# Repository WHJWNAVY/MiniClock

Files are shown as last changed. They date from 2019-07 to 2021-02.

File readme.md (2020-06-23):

# MIniClock

## 美图欣赏

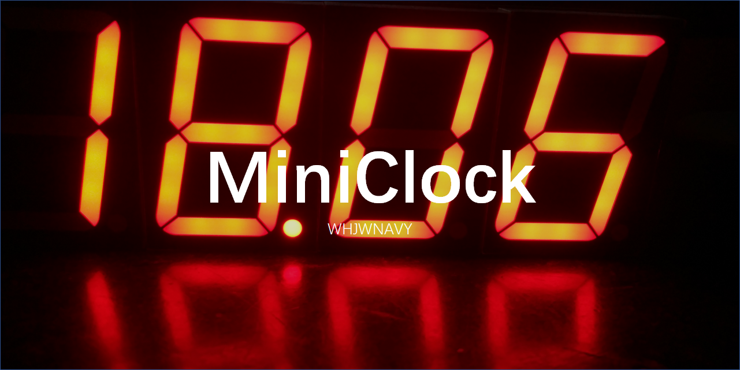
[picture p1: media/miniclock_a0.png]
MiniClock

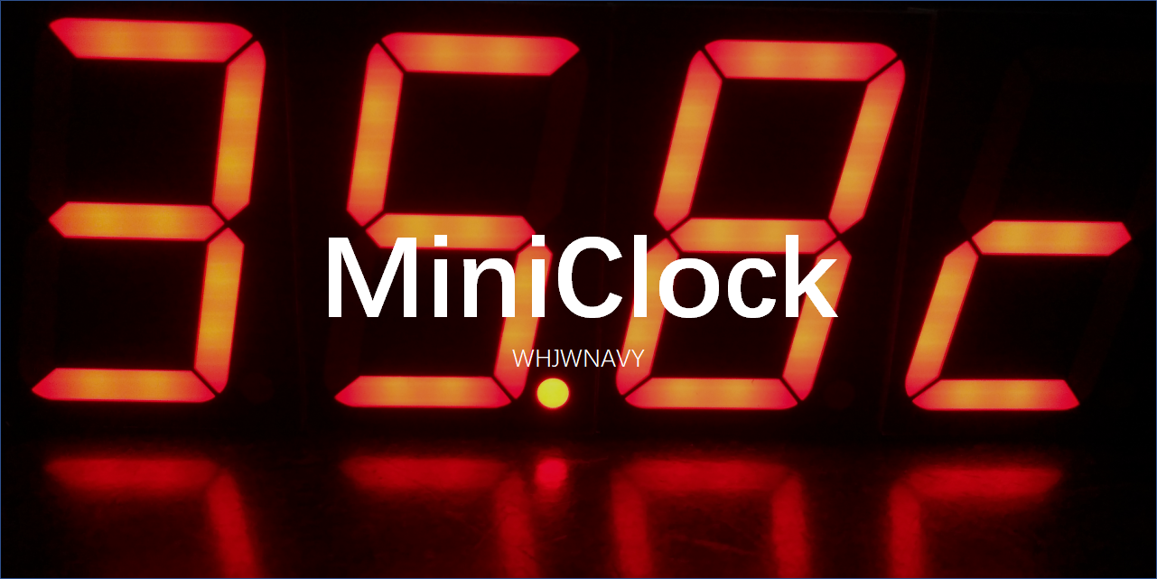
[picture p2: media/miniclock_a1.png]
MiniClock


## 实物图
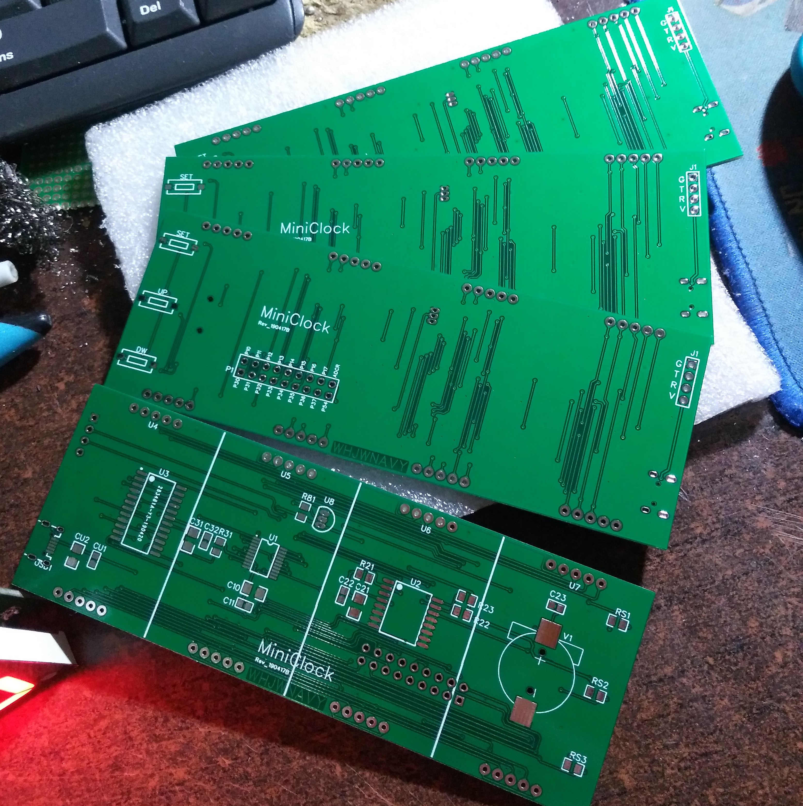
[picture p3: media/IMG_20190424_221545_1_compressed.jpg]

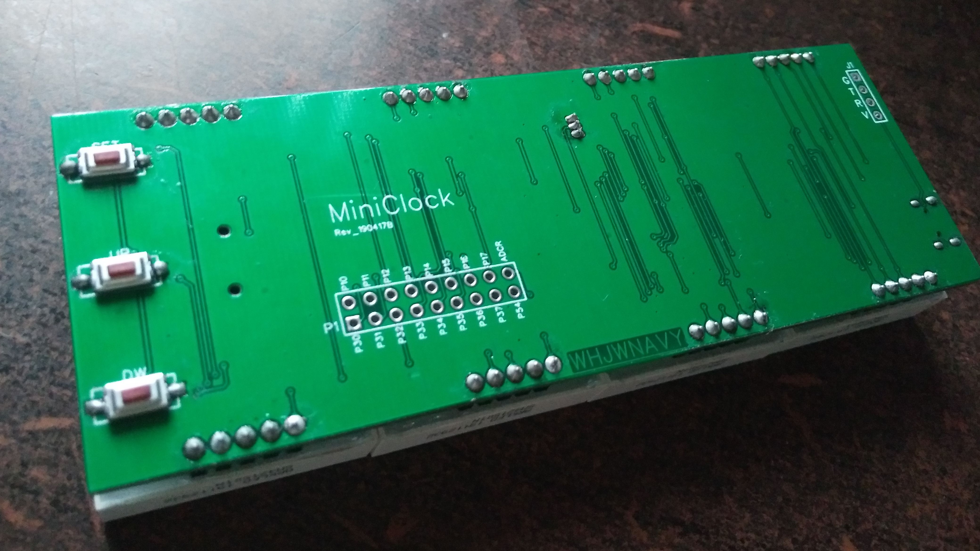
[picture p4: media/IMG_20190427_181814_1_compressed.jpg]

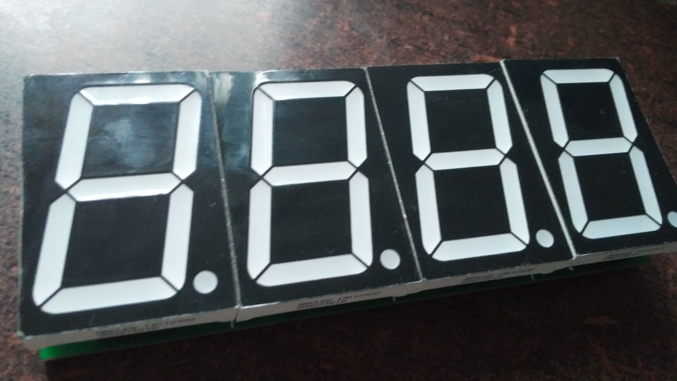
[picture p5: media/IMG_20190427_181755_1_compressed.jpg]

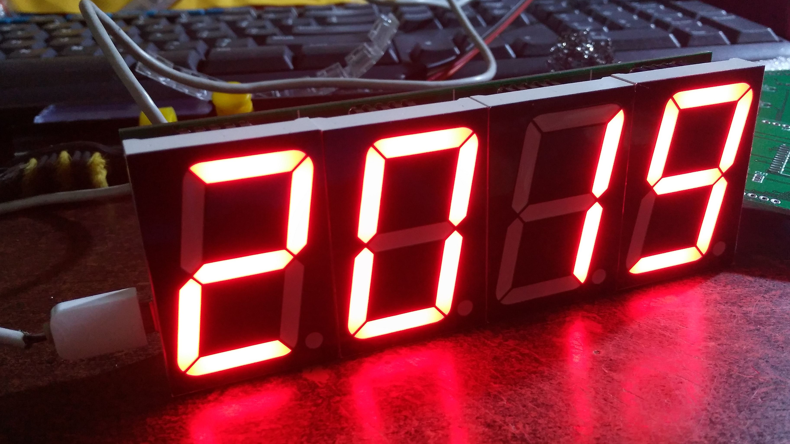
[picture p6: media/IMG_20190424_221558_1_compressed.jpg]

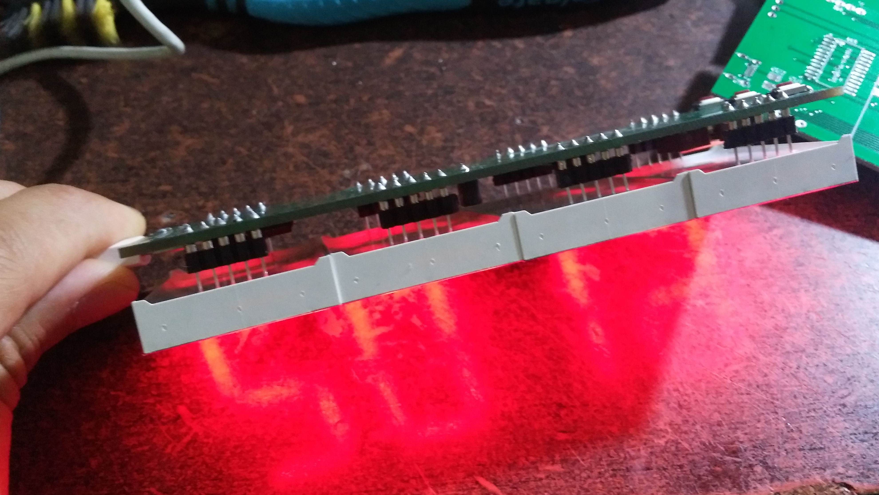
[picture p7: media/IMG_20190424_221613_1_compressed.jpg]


## 原理图&PCB

* ***[MiniClock_SCH_01_190419B.pdf](./doc/MiniClock_SCH_01_190419B.pdf)***

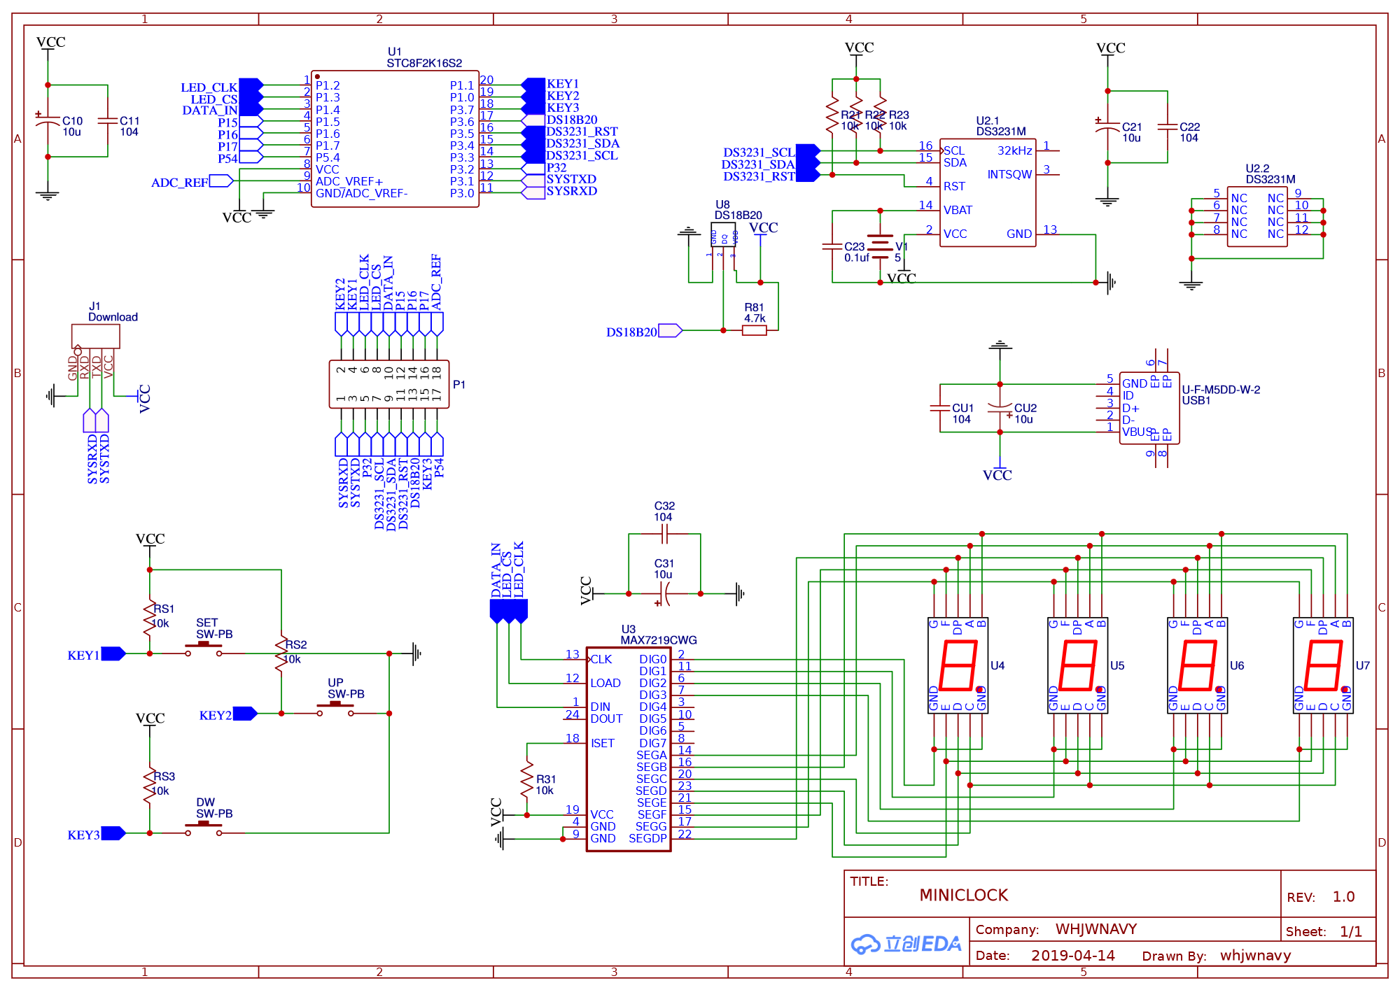
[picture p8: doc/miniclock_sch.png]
MiniClock


* ***[Gerber_MINICLOCK_PCB_02_20190419231404.zip](./doc/MiniClock_PCB_Rev190417B/Gerber_MINICLOCK_PCB_02_20190419231404.zip)***

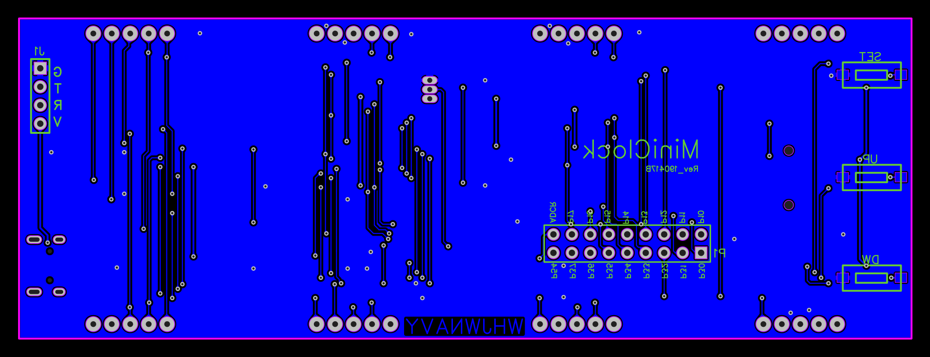
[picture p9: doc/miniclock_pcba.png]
MiniClock

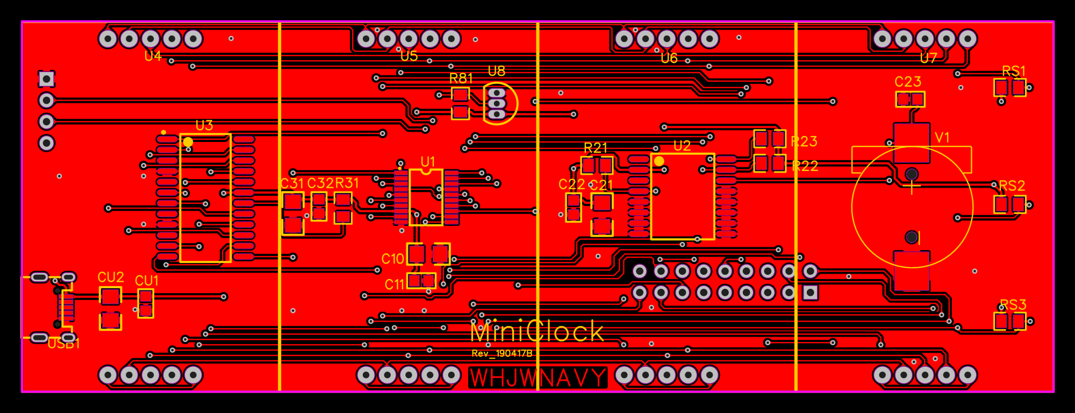
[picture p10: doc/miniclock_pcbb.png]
MiniClock


* ***[LCEDA OpenHW PCB & SCH](https://lceda.cn/whjwnavy/led-miniclock)***

## 页面逻辑

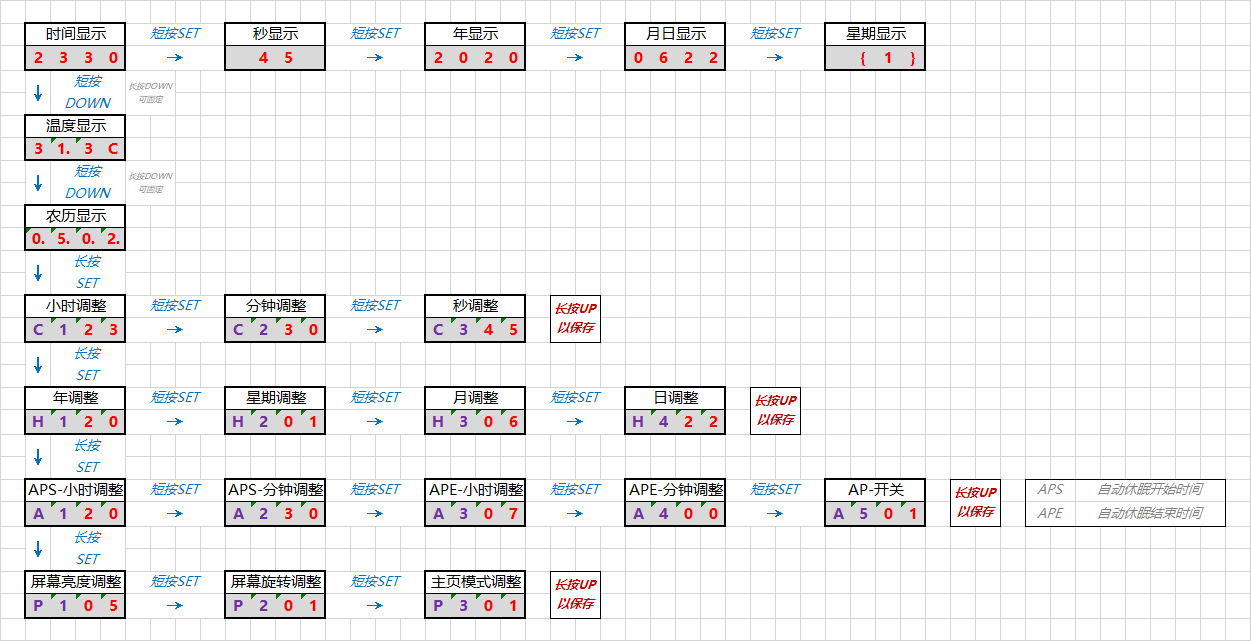
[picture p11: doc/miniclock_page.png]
MiniClock


## 设置代码

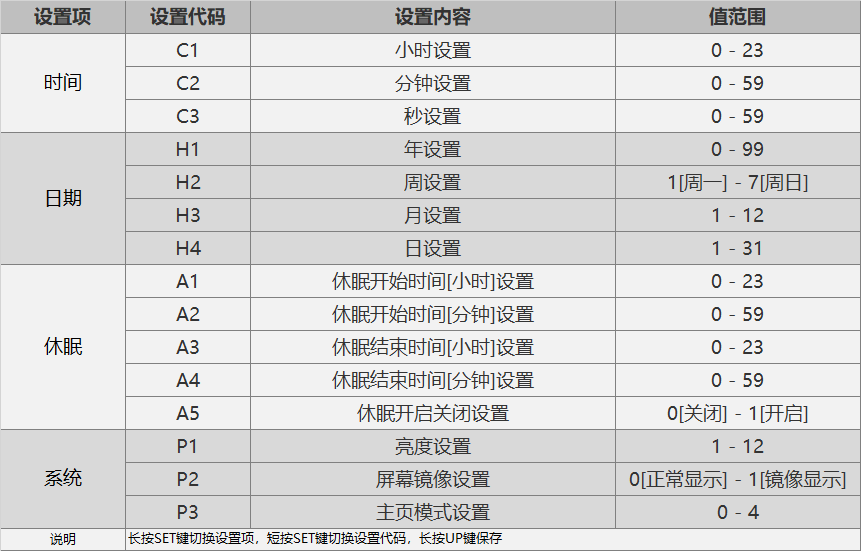
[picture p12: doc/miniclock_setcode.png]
MiniClock


# 使用说明

## 查看

### 查看时间,日历

* 开机后默认显示 **[小时-分钟]** , 底部四个点循环滚动代表秒
* 短按 **Set** 键可以查看 **[秒]**
* 再次短按 **Set** 键可以查看 **[年]**
* 再次短按 **Set** 键可以查看 **[月-日]**
* 再次短按 **Set** 键可以查看 **[星期]** , 1代表周一, 7代表周日
* 15秒内无操作自动回到 **[小时-分钟]** 显示界面

> ***小提示1***
>
> 实际上在 **[小时-分钟]** 显示界面下, 连续短按 **Set** 键, 会依次在 **[小时-分钟] - [秒] - [年] - [月-日] - [星期]** 间循环切换

### 查看温度,农历

* 在 **[小时-分钟]** 显示模式下, 短按 **Up** 键可以查看 **[温度]**
* 再次短按 **Up** 键, 可以查看 **[农历月-日]**
* 在时间显示模式下, 短按 **Dwn** 键可以查看 **[农历月-日]**
* 再次短按 **Dwn** 键, 可以查看 **[温度]**
* 15秒内无操作自动回到 **[小时-分钟]** 显示界面

> ***小提示2***:
>
> 长按(***1秒以上***)一次 **Up** 键可以固定显示温度, 15秒无操作不会退回时间显示界面, 再次短按 **Up*** 或 ***Down** 键可以取消固定

> ***小提示3***
>
> 长按(***1秒以上***)一次 **Dwn** 键可以固定显示农历, 15秒无操作不会退回时间显示界面, 再次短按 **Up*** 或 ***Down** 键可以取消固定

> ***小提示4***
>
> 实际上在 **[小时-分钟]** 显示界面下,连续短按 **Up** 键或 **Dwn** 键, 会依次在 **[小时-分钟] - [温度] - [农历月-日]** 间循环切换

### 待机/休眠模式

* 在 **[小时-分钟]** 显示模式下, 长按(***8秒以上***) **Set** 键可以待机/休眠
* 按任意键结束待机/休眠

## 设置
* 在时间或温度显示界面下, 长按(***1秒以上***) **Set** 键进入 **[设置界面]**
* 设置模式下, 前两位表示 **[设置代码]** ,后两位表示 **[设置值]**
* 设置代码第一位表示 **[主设置项]** , 第二位表示 **[次设置项]**
* 长按(***1秒以上***) **Set** 键切换 **[主设置项]**
* 短按 **Set** 键切换 **[次设置项]**
* 长按(***1秒以上***) **Up** 键保存调整之后的值
* 15秒内无操作自动回到 **[小时-分钟]** 显示界面

> ***小提示5***
>
> 设置值发生改变后会闪烁
>
> 切换主设置项后, 不会自动保存之前的更改
>
> 在 **[系统设置P]** 模式下, 再次长按(***1秒以上***) **Set** 键会回到 **[小时-分钟]** 显示界面

> ***小提示6***
>
> 模式自动休眠开始时间为22:30，结束时间为7:30，MiniClock会在22:30关闭显示界面，直到7:30
>
> MiniClock会在到达你设置的开始时间时关闭显示界面，在到达你设置的结束时间时开启显示界面

> ***小提示7***
>
> 默认的显示模式为正常模式[***0***]，开启旋转显示模式[***1***]后，屏幕内容会旋转180°显示

### 设置代码表

| 主设置项 | 设置代码 | 设置内容 | 值范围 |
| :---: | :---: | :---: | :---: |
| 时间 | C1 | 小时设置 | 0 - 23 |
| | C2 | 分钟设置 | 0 - 59 |
| | C3 | 秒设置 | 0 - 59 |
| 日期 | H1 | 年设置 | 0 - 99 |
| | H2 | 周设置 | 1[周一] - 7[周日] |
| | H3 | 月设置 | 1 - 12 |
| | H4 | 日设置 | 1 - 31 |
| 休眠 | A1 | 休眠开始时间[小时]设置 | 0 - 23 |
| | A2 | 休眠开始时间[分钟]设置 | 0 - 59 |
| | A3 | 休眠结束时间[小时]设置 | 0 - 23 |
| | A4 | 休眠结束时间[分钟]设置 | 0 - 59 |
| | A5 | 休眠开启关闭设置 | 0[关闭] - 1[开启] |
| 系统 | P1 | 亮度设置 | 1 - 12 |
| | P2 | 屏幕镜像设置 | 0[正常显示] - 1[镜像显示] |

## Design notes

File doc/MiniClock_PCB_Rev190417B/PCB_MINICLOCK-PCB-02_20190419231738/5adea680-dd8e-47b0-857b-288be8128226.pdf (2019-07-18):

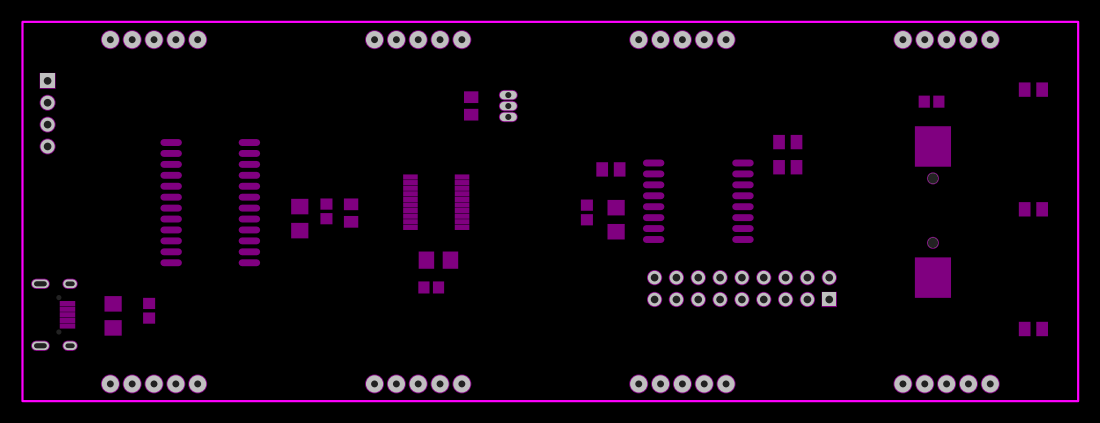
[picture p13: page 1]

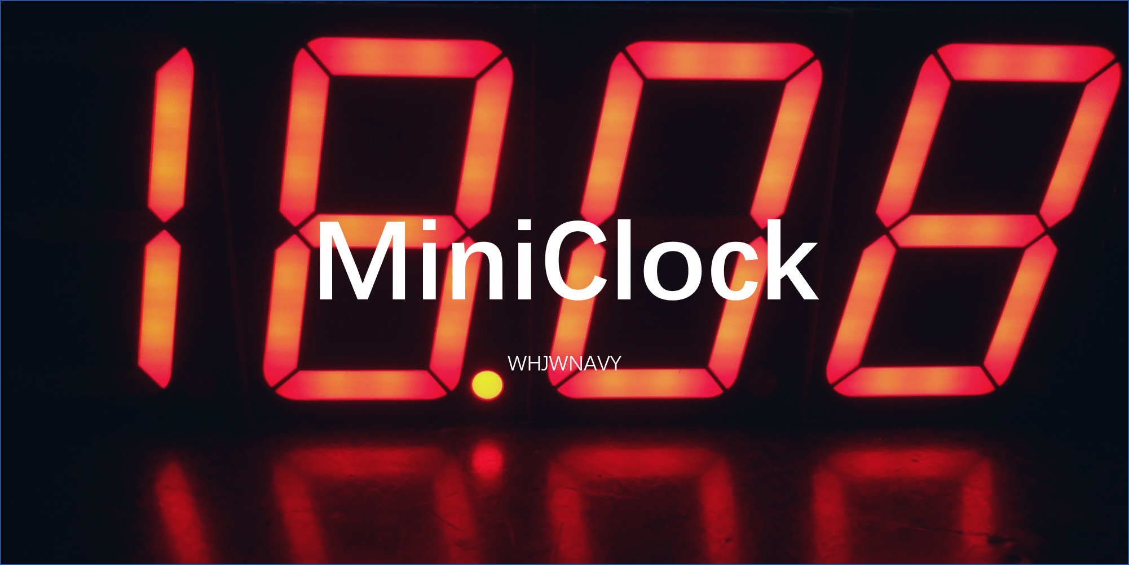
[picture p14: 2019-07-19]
media/MiniClock.png

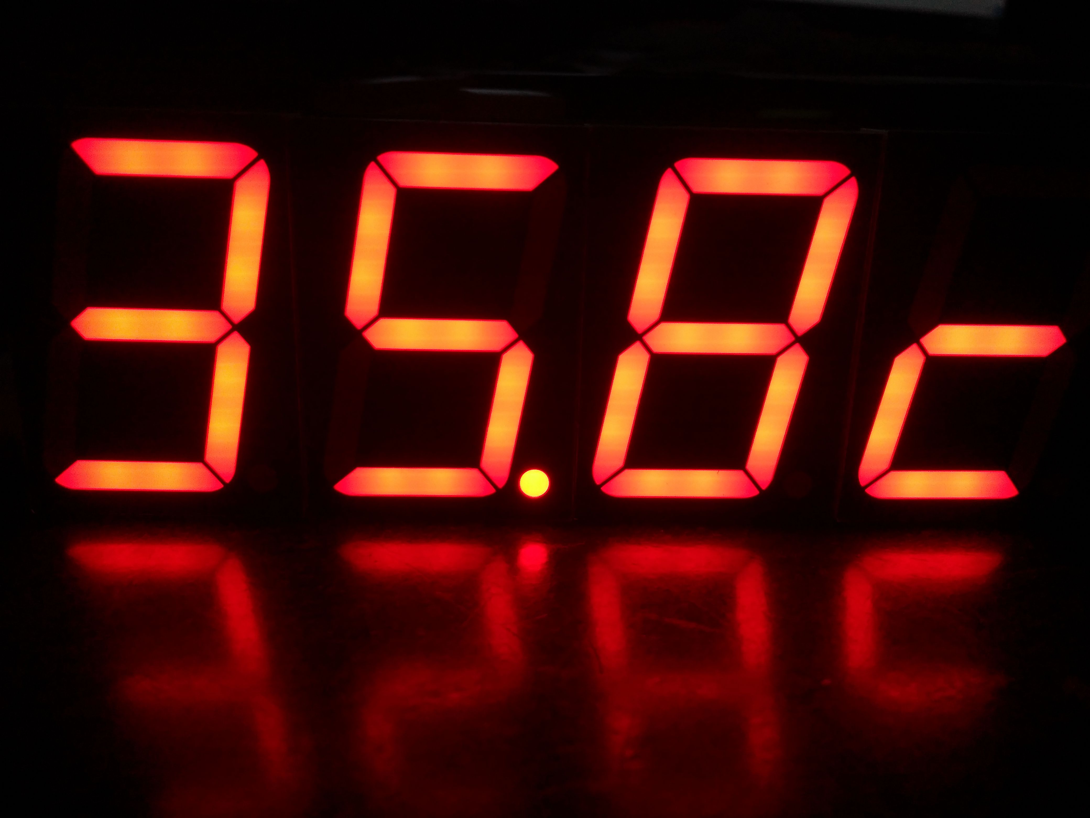
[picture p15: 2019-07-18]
media/IMG_20190427_180651_1_compressed.jpg

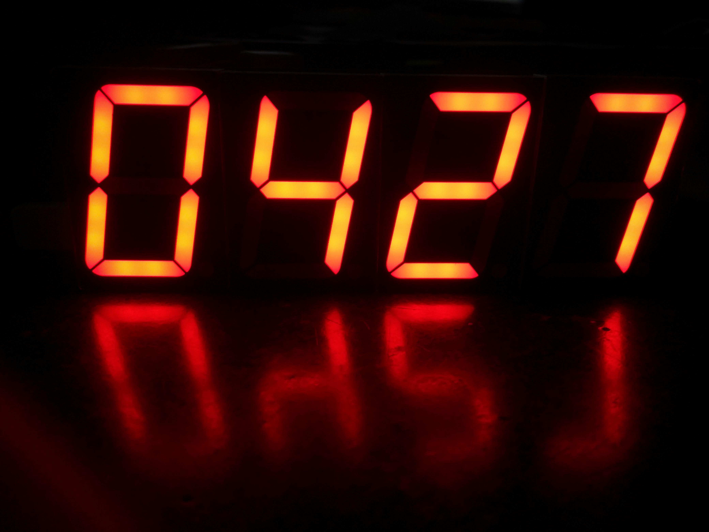
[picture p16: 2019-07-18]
media/IMG_20190427_180931_compressed.jpg

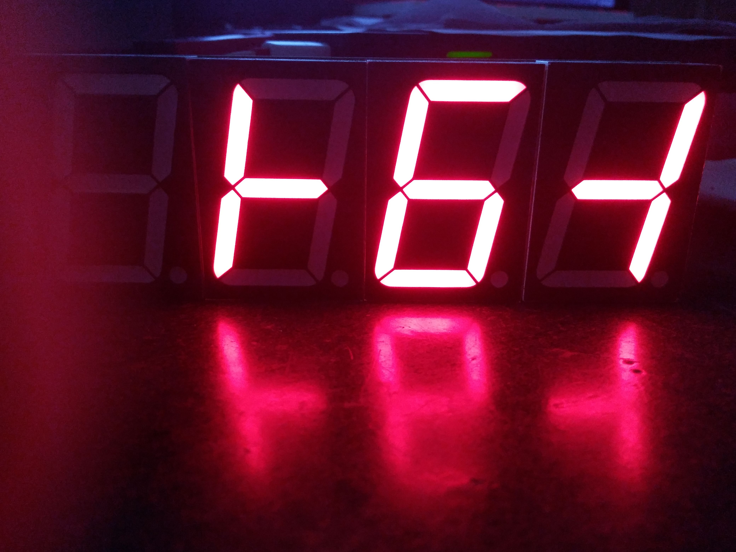
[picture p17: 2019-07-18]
media/IMG_20190427_180738_1_compressed.jpg

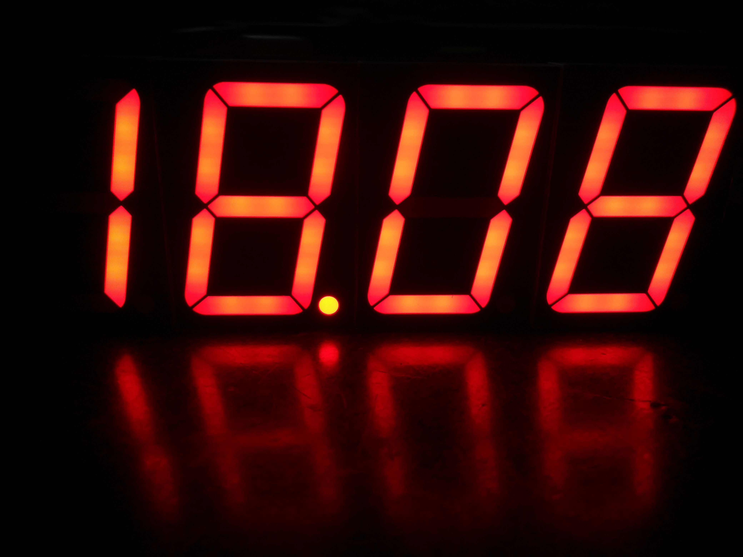
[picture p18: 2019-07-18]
media/MiniClock_big.jpg

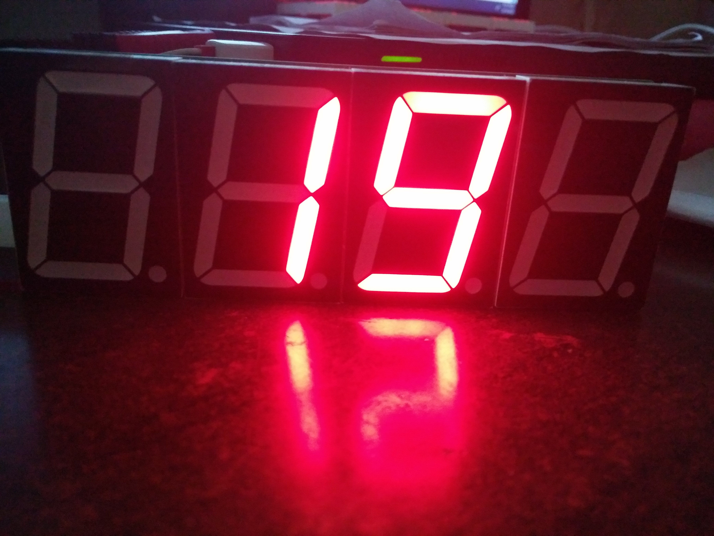
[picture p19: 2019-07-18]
media/IMG_20190427_180916_compressed.jpg

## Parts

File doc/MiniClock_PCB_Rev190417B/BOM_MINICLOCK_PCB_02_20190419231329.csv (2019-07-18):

ID | Name | Designator | Footprint | Quantity | Manufacturer Part | Manufacturer | Supplier | Supplier Part
1 | STC8F2K16S2 | U1 | TSSOP-20 | 1 | STC8F2K16S2 | STC | LCSC | C128772
2 | 10k | R23,R22,R21,R31,RS1,RS2,RS3 | 0805' | 7 | ?
3 | 0.1uf | C23 | C0603 | 1 | ?
4 | 5 | V1 | BATTERY-2 | 1 | ?
5 | 10u | C21,C10,C31,CU2 | 1206 | 4 | ?
6 | 104 | C22,C11,C32,CU1 | C0603 | 4 | ?
7 | MAX7219CWG | U3 | SOIC-24_300MIL | 1 | MAX7219CWG | MAXIM | LCSC | C9964
8 | SW-PB | SET,UP,DW | KEY-3.0*6.0 | 3 | ?
9 | Download | J1 | H4-2.54-UART | 1 | P125-1104A0BS116A1
10 | U-F-M5DD-W-2 | USB1 | MICRO-USB-A17 | 1 | U-F-M5DD-W-2 | HRO | LCSC | C145793
11 | DS18B20 | U8 | 18B20 | 1 | ?
12 | 4.7k | R81 | 0805' | 1 | ?
13 | SM421501 | U4,U5,U6,U7 | SM411501 | 4 | SM411501
14 | Header-Female-2.54_2x9 | P1 | HDR-9X2/2.54 | 1 | Header-Female-2.54_2x9 | BOOMELE | LCSC | C71956
15 | DS3231M | U2 | SOIC-16_300MIL | 1 | DS3231M+TRL | MAXIM | LCSC | C37663

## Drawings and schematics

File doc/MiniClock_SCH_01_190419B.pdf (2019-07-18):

## VCC VCC

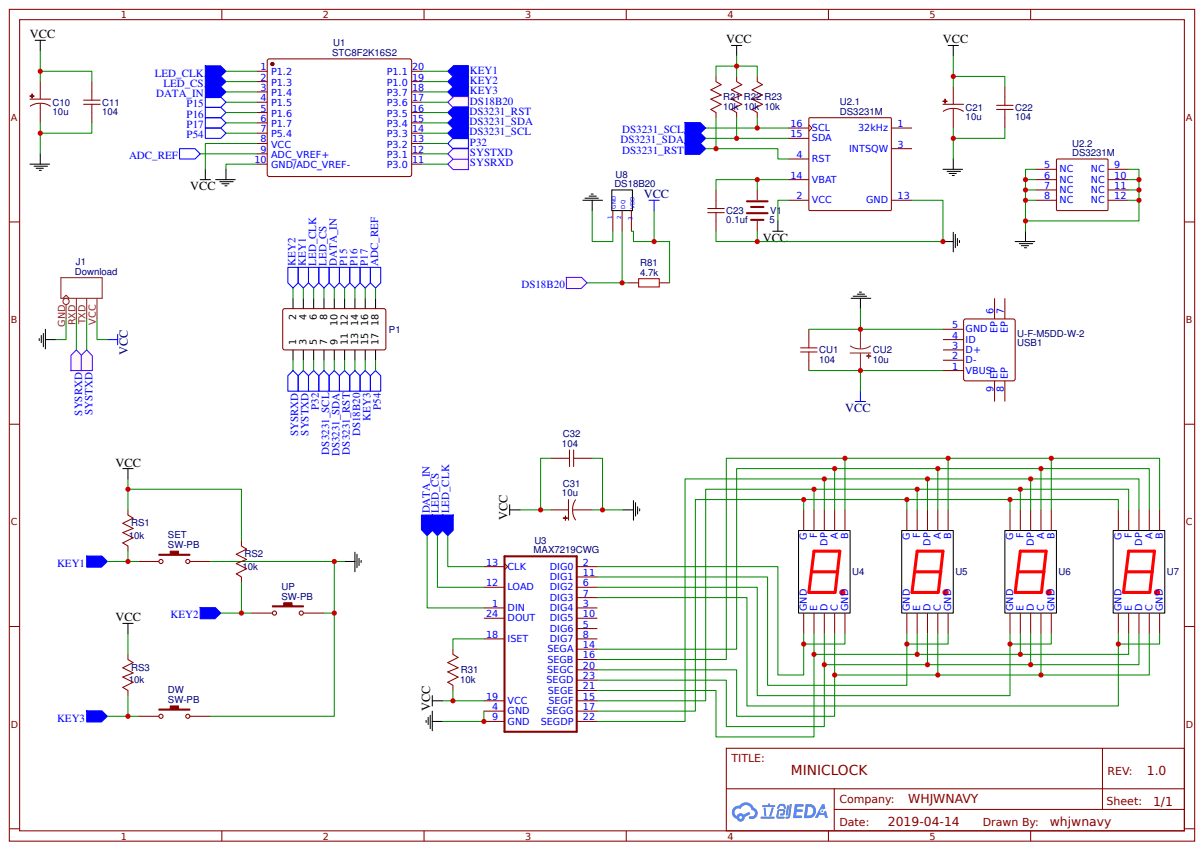
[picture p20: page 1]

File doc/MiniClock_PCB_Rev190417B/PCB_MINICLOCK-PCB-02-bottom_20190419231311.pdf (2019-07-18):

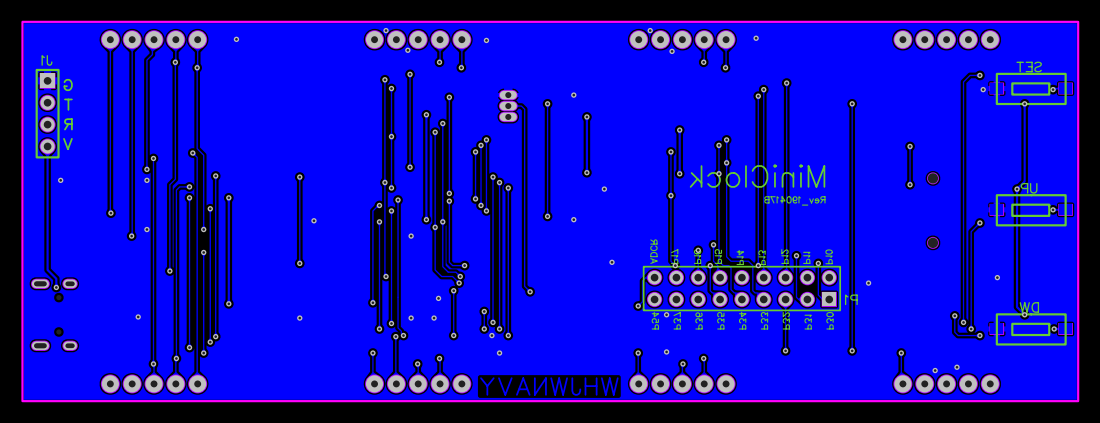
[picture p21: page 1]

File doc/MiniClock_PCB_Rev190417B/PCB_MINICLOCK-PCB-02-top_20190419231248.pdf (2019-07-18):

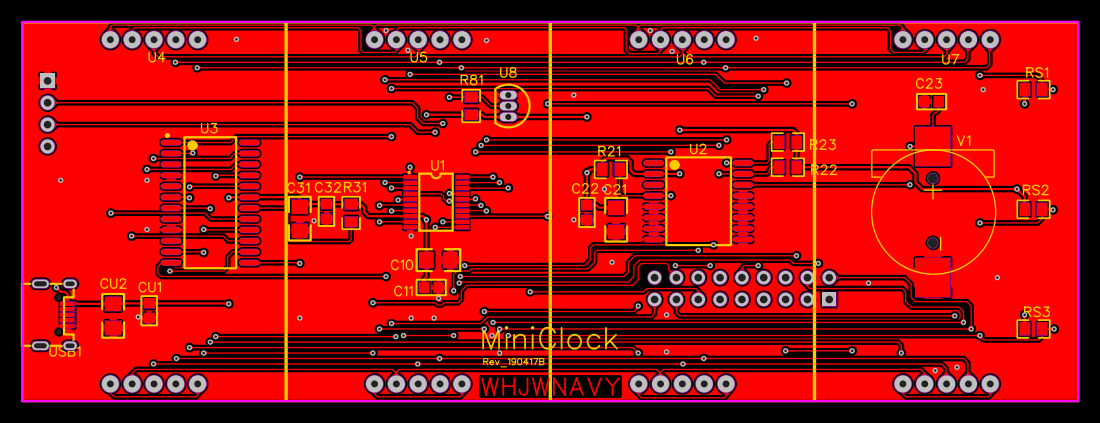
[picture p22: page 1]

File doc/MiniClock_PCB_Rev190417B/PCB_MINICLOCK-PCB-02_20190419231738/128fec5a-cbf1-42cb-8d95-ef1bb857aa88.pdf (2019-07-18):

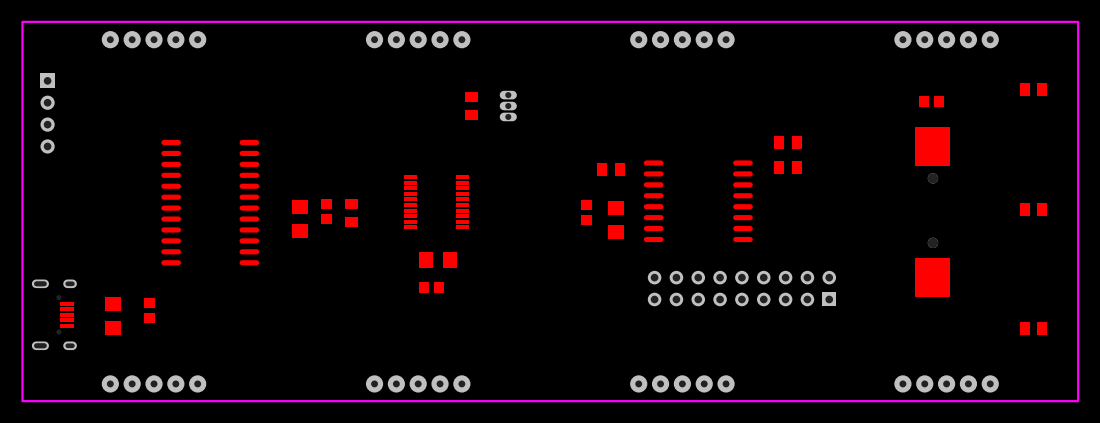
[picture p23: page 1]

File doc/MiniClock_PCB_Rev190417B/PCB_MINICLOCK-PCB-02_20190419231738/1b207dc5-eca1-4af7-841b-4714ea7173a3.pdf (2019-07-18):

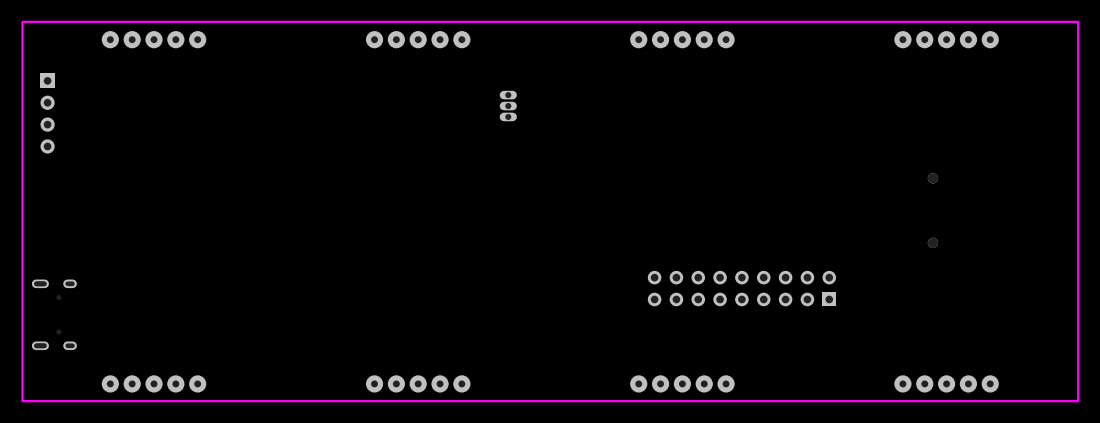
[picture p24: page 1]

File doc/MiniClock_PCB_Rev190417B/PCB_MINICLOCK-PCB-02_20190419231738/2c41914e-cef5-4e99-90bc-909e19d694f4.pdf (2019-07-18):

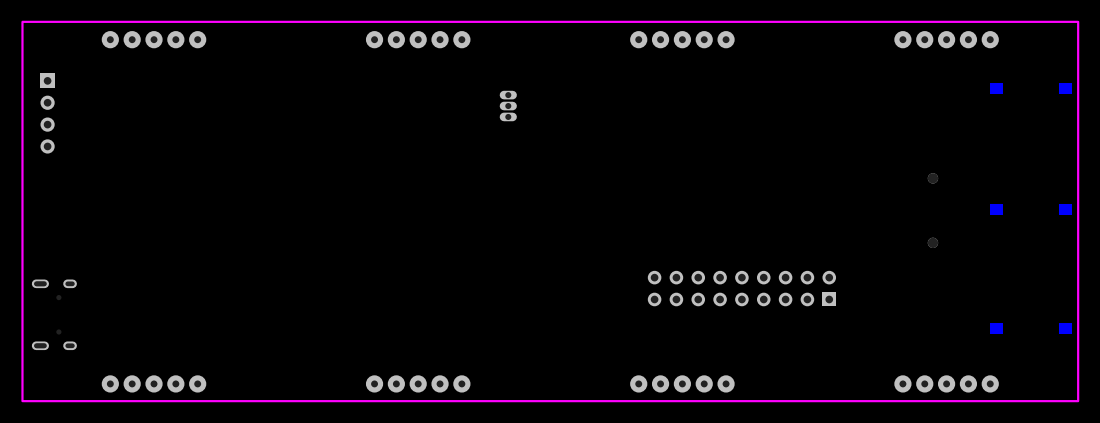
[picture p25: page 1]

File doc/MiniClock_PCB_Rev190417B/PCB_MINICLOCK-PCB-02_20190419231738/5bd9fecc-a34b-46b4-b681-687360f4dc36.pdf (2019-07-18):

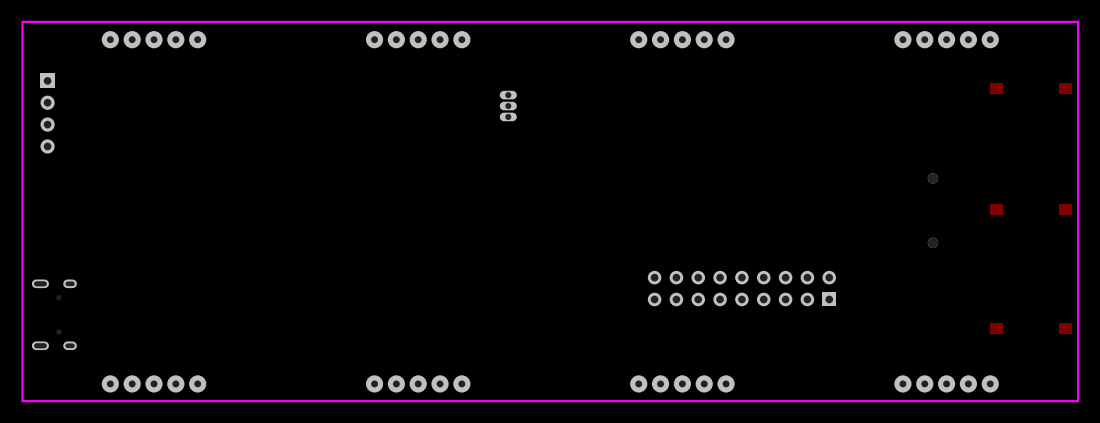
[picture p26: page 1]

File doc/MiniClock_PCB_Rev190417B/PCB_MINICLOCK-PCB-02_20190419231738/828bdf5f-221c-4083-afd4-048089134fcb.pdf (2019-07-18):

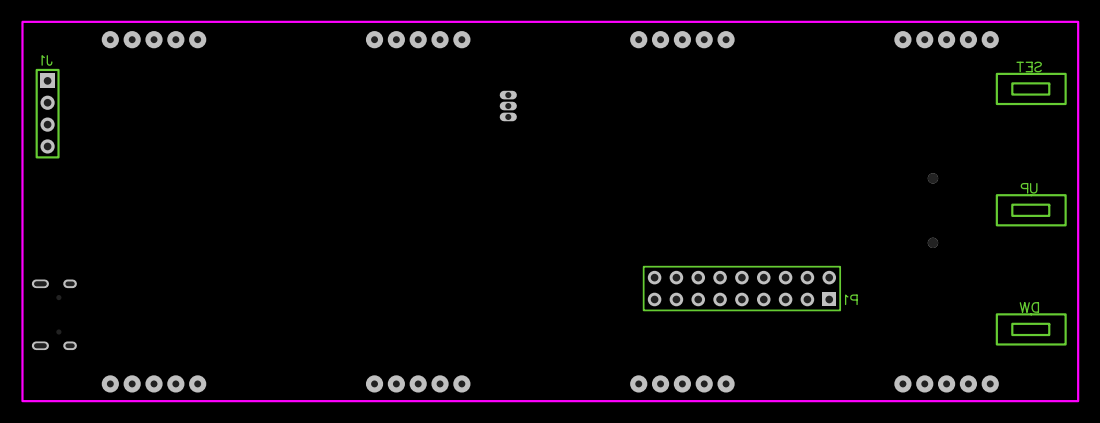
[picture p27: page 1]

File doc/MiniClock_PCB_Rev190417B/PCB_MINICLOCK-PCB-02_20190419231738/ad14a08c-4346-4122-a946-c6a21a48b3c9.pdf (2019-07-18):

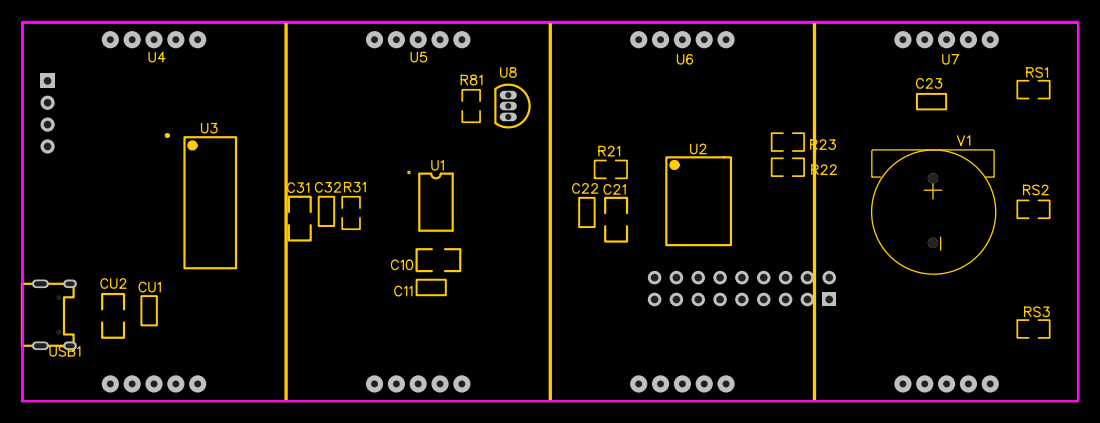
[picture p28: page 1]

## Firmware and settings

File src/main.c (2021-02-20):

#include "common.h"
#include "drv_led.h"
#include "drv_key.h"
#include "drv_3231.h"
#include "china_nonli.h"
#include "drv_18b20.h"

#include "drv_cfg.h"

#define DEF_SYS_LED_FPS (100u)
#define DEF_SYS_LED_FLASH (3u)
#define DEF_SYS_LED_MIRROR (0u)

#define DEF_SYS_MAIN_MODE (4u)
#define SYS_MAIN_MODE_MAX (4u)

#define DEF_SYS_AUTOEXIT_TMR (150u)
#define DEF_SYS_LED_LIGHT (5u)
#define DEF_SYS_AUTO_SLEEP (1u)

#define DEF_SYS_REMIND_DELAY (20u)
#define DEF_SYS_REMIND_TMR (10u)

//菜单列表
typedef enum page_mode_e {
    PAGE_MENU_MIN = 0x1Au,
    PAGE_MENU_MAIN = PAGE_MENU_MIN, //主界面
    PAGE_MENU_STIME,                //时间设置界面
    PAGE_MENU_SDATE,                //日期设置界面
    PAGE_MENU_SATSLEEP,             //自动休眠设置
    PAGE_MENU_SYSCFG,               //系统设置
    PAGE_MENU_MAX,
    PAGE_MENU_POWER,
    PAGE_MENU_REMIND,
} page_mode_e;

//计时模式
typedef enum main_mode_e {
    MAIN_MODE_MIN = 0x20u,
    MAIN_MODE_TIME = MAIN_MODE_MIN, // time
    MAIN_MODE_TEMP,                 // temp
    MAIN_MODE_NONLI,                // nonli
    MAIN_MODE_MAX,
} main_mode_t;

//主页切换
typedef enum main_page_e {
    MAIN_PAGE_MIN = 0x2Au,
    MAIN_PAGE_HHMM = MAIN_PAGE_MIN, // hour - minute
    MAIN_PAGE_TTSS,                 // am/pm - second
    MAIN_PAGE_YYYY,                 // year
    MAIN_PAGE_MMDD,                 // month - day
    MAIN_PAGE_DDDD,                 // week
    MAIN_PAGE_MAX,
} main_page_t;

//时间设置界面
typedef enum set_time_page_e {
    SET_TIME_PAGE_MIN = 0x3Au,
    SET_TIME_PAGE_HOUR = SET_TIME_PAGE_MIN, // hour
    SET_TIME_PAGE_MINUTE,                   // minute
    SET_TIME_PAGE_SECOND,                   // second
    SET_TIME_PAGE_MAX,
} set_time_page_t;

//日期设置界面
typedef enum set_date_page_e {
    SET_DATE_PAGE_MIN = 0x4Au,
    SET_DATE_PAGE_YEAR = SET_DATE_PAGE_MIN, // year
    SET_DATE_PAGE_WEEK,                     // week
    SET_DATE_PAGE_MONTH,                    // month
    SET_DATE_PAGE_DAY,                      // day
    SET_DATE_PAGE_MAX,
} set_date_page_t;

typedef enum set_system_page_e {
    SET_SYSTEM_PAGE_MIN = 0x50u,
    SET_SYSTEM_PAGE_LIGHT = SET_SYSTEM_PAGE_MIN,
    SET_SYSTEM_PAGE_MIRROR,
    SET_SYSTEM_PAGE_SECMOD,
    SET_SYSTEM_PAGE_MAX,
} set_system_page_t;

//加减操作
typedef enum set_oper_e {
    SET_OPER_MIN = 0x5Au,
    SET_OPER_ADD,
    SET_OPER_SUB,
    SET_OPER_MAX,
} set_oper_t;

//日期设置界面
typedef enum set_auto_sleep_e {
    SET_AUTO_SLEEP_MIN = 0x6Au,
    SET_AUTO_SLEEP_SHOUR = SET_AUTO_SLEEP_MIN,
    SET_AUTO_SLEEP_SMINUTE,
    SET_AUTO_SLEEP_EHOUR,
    SET_AUTO_SLEEP_EMINUTE,
    SET_AUTO_SLEEP_ON,
    SET_AUTO_SLEEP_MAX,
} set_auto_sleep_t;

typedef struct auto_sleep_s {
    uint8 s_hour;
    uint8 s_min;
    uint8 e_hour;
    uint8 e_min;
    uint8 on;
} auto_sleep_t;

typedef struct system_cfg_e {
    uint8 led_light;
    uint8 led_mirror;
    uint8 main_mode;
    auto_sleep_t autosleep;
} system_cfg_t;

#define SYSTEM_CFG_SIZE                                                                                                \
    ((SET_SYSTEM_PAGE_MAX - SET_SYSTEM_PAGE_MIN) + (SET_AUTO_SLEEP_MAX - SET_AUTO_SLEEP_MIN)) // sizeof(sys_cfg_t)

void system_cfg_init(system_cfg_t *cfg) {
    if (cfg != NULL) {
        cfg->led_light = DEF_SYS_LED_LIGHT;
        cfg->led_mirror = DEF_SYS_LED_MIRROR;
        cfg->main_mode = DEF_SYS_MAIN_MODE;
        cfg->autosleep.on = DEF_SYS_AUTO_SLEEP;
        cfg->autosleep.s_hour = 22;
        cfg->autosleep.s_min = 30;
        cfg->autosleep.e_hour = 7;
        cfg->autosleep.e_min = 30;
    }
}

uint8 system_cfg_write(system_cfg_t *cfg) {
    uint8 ret = RTN_ERR;
    if (cfg != NULL) {
        ret = cfgsave_write((uint8 *)cfg,
                            /*sizeof(system_cfg_t)*/ SYSTEM_CFG_SIZE);
    }

    return ret;
}

uint8 system_cfg_read(system_cfg_t *cfg) {
    uint8 ret = RTN_ERR;
    if (cfg != NULL) {
        ret = cfgsave_read((uint8 *)cfg,
                           /*sizeof(system_cfg_t)*/ SYSTEM_CFG_SIZE);
    }

    return ret;
}

uint8 system_cfg_copy(system_cfg_t *dst, system_cfg_t *src) {
    uint8 ret = RTN_ERR;
    if ((dst != NULL) && (src != NULL) && (src != dst)) {
        dst->led_light = src->led_light;
        dst->led_mirror = src->led_mirror;
        dst->main_mode = src->main_mode;
        dst->autosleep.on = src->autosleep.on;
        dst->autosleep.s_hour = src->autosleep.s_hour;
        dst->autosleep.s_min = src->autosleep.s_min;
        dst->autosleep.e_hour = src->autosleep.e_hour;
        dst->autosleep.e_min = src->autosleep.e_min;
        ret = RTN_OK;
    }

    return ret;
}

void system_cfg_apply(system_cfg_t *cfg) {
    if (cfg != NULL) {
        led_set_light(cfg->led_light);
        led_set_mirror(cfg->led_mirror);
        key_set_mirror(cfg->led_mirror);
    }
}

void _menu_data_deal_(uchar *dat, uchar op, uchar max, uchar min) {
    char data_t = 0;
    if ((op == SET_OPER_ADD) || (op == SET_OPER_SUB)) {
        data_t = (char)(*dat);
        if (op == SET_OPER_ADD) //加
        {
            data_t++;
            if (data_t > max) {
                data_t = min;
            }
        } else if (op == SET_OPER_SUB) ///减
        {
            data_t--;
            if (data_t < min) {
                data_t = max;
            }
        }
        *dat = (uchar)data_t;
    }
}

void show_hhmm_second(uchar second, uchar mode) {
    uchar n = 0, m = 0;
    switch (mode) {
    case 1: {
        /* ---- */
        /* X--- */
        /* XX-- */
        /* XXX- */
        /* XXXX */
        m = ((second) % (LED_POS_MAX + 1));
        if (m < LED_POS_MAX) {
            for (n = 0; n < LED_POS_MAX; n++) {
                if (n <= m) {
                    led_putb(n, LED_SEGB_SET(LED_SEGB_DP), 1, 1);
                } else {
                    led_putb(n, LED_SEGB_SET(LED_SEGB_DP), 0, 1);
                }
            }
        } else {
            for (n = 0; n < LED_POS_MAX; n++) {
                led_putb(n, LED_SEGB_SET(LED_SEGB_DP), 0, 1);
            }
        }
    } break;
    case 2: {
        /* -X-- */
        /* -O-- */
        n = (LED_POS_MAX / 2) - 1;
        if (((second) % 2) == 0) {
            led_putb(n, LED_SEGB_SET(LED_SEGB_DP), 1, 1);
        } else {
            led_putb(n, LED_SEGB_SET(LED_SEGB_DP), 0, 1);
        }
    } break;
    case 3: {
        /* XXOO */
        /* OOXX */
        m = ((second) % 2);
        for (n = 0; n < LED_POS_MAX; n++) {
            if (n < (LED_POS_MAX / 2)) {
                led_putb(n, LED_SEGB_SET(LED_SEGB_DP), m, 1);
            } else {
                led_putb(n, LED_SEGB_SET(LED_SEGB_DP), !m, 1);
            }
        }
    } break;
    case 4: {
        /* XOOX */
        /* OXXO */
        m = ((second) % 2);
        for (n = 0; n < LED_POS_MAX; n++) {
            if ((n % (LED_POS_MAX - 1)) == 0) {
                led_putb(n, LED_SEGB_SET(LED_SEGB_DP), m, 1);
            } else {
                led_putb(n, LED_SEGB_SET(LED_SEGB_DP), !m, 1);
            }
        }
    } break;
    default: {
        /* X--- */
        /* -X-- */
        /* --X- */
        /* ---X */
        for (n = 0; n < LED_POS_MAX; n++) {
            if (((second) % LED_POS_MAX) == n) {
                led_putb(n, LED_SEGB_SET(LED_SEGB_DP), 1, 1);
            } else {
                led_putb(n, LED_SEGB_SET(LED_SEGB_DP), 0, 1);
            }
        }
    } break;
    }
}

void show_main_page(rtc_time_t *tm, uchar page, uchar mode) {
    uchar n = 0, m = 0;
    char xdata disp_str[LED_POS_MAX + 1] = {0};
    if (tm == NULL) {
        return;
    }

    switch (page) {
    case MAIN_PAGE_HHMM:
        tm->hour = tm->hour % 100;
        tm->minute = tm->minute % 100;

        led_puti(0, (tm->hour / 10), 1);
        led_puti(1, (tm->hour % 10), 1);
        led_puti(2, (tm->minute / 10), 1);
        led_puti(3, (tm->minute % 10), 1);

        // sprintf(disp_str, "%bu%bu%bu%bu", (tm->hour / 10), (tm->hour %
        // 10),
        //    (tm->minute / 10), (tm->minute % 10));
        // led_puts(0, disp_str, 1);
        show_hhmm_second(tm->second, mode);
        break;
    case MAIN_PAGE_TTSS:
        tm->second = tm->second % 100;

        led_puti(0, LED_SEG_NULL, 1);
        led_puti(1, (tm->second / 10), 1);
        led_puti(2, (tm->second % 10), 1);
        led_puti(3, LED_SEG_NULL, 1);

        // sprintf(disp_str, " %bu%bu ", (tm->second / 10), (tm->second %
        // 10)); led_puts(0, disp_str, 1);
        break;
    case MAIN_PAGE_YYYY:
        tm->year = tm->year % 100;

        led_puti(0, 2, 1);
        led_puti(1, 0, 1);
        led_puti(2, (tm->year / 10), 1);
        led_puti(3, (tm->year % 10), 1);

        // sprintf(disp_str, "20%bu%bu", (tm->year / 10), (tm->year % 10));
        // led_puts(0, disp_str, 1);
        break;
    case MAIN_PAGE_MMDD:
        tm->month = tm->month % 100;
        tm->day = tm->day % 100;

        led_puti(0, (tm->month / 10), 1);
        led_puti(1, (tm->month % 10), 1);
        led_puti(2, (tm->day / 10), 1);
        led_puti(3, (tm->day % 10), 1);

        // sprintf(disp_str, "%bu%bu%bu%bu", (tm->month / 10), (tm->month %
        // 10),
        //    (tm->day / 10), (tm->day % 10));
        // led_puts(0, disp_str, 1);
        break;
    case MAIN_PAGE_DDDD:
        tm->week = tm->week % 100;

        led_puti(0, (LED_SEG_NULL), 1);
        led_puti(1, (LED_SEG_HL), 1);
        led_puti(2, (tm->week % 10), 1);
        led_puti(3, (LED_SEG_HL), 1);

        // sprintf(disp_str, " {%bu}", /*(((tm->week % 10) > 5) ? "-" : "
        // "),*/
        //    (tm->week % 10));
        // led_puts(0, disp_str, 1);
        break;
    default:
        break;
    }
}

void show_time_set_page(rtc_time_t *tm, uchar page, uchar op) {
    uchar dat = 0;
    char xdata disp_str[LED_POS_MAX + 1] = {0};

    if (tm == NULL) {
        return;
    }

    switch (page) {
    case SET_TIME_PAGE_HOUR:
        dat = tm->hour;
        _menu_data_deal_(&dat, op, 23, 0);
        tm->hour = dat;
        break;
    case SET_TIME_PAGE_MINUTE:
        dat = tm->minute;
        _menu_data_deal_(&dat, op, 59, 0);
        tm->minute = dat;
        break;
    case SET_TIME_PAGE_SECOND:
        dat = tm->second;
        _menu_data_deal_(&dat, op, 59, 0);
        tm->second = dat;
        break;
    default:
        break;
    }

    page = page - SET_TIME_PAGE_MIN;

    disp_str[0] = LED_SEG_C;

    // page %= (LED_SEG_SG - LED_SEG_SA + 1);
    disp_str[1] = page + 1;

    // dat %= 100;
    disp_str[2] = dat / 10;
    disp_str[3] = dat % 10;
    led_putis(0, disp_str, LED_POS_MAX, 1);
}

void show_date_set_page(rtc_time_t *tm, uchar page, uchar op) {
    uchar n = 0;
    uchar dat = 0;
    char xdata disp_str[LED_POS_MAX + 1] = {0};

    if (tm == NULL) {
        return;
    }

    switch (page) {
    case SET_DATE_PAGE_YEAR:
        dat = tm->year;
        _menu_data_deal_(&dat, op, 99, 0);
        tm->year = dat;
        break;
    case SET_DATE_PAGE_MONTH:
        dat = tm->month;
        _menu_data_deal_(&dat, op, 12, 1);
        tm->month = dat;
        break;
    case SET_DATE_PAGE_DAY:
        dat = tm->day;
        _menu_data_deal_(&dat, op, 31, 1);
        tm->day = dat;
        break;
    case SET_DATE_PAGE_WEEK:
        n = 1;
        dat = tm->week;
        _menu_data_deal_(&dat, op, 7, 1);
        tm->week = dat;
        break;
    default:
        break;
    }

    page = page - SET_DATE_PAGE_MIN;

    disp_str[0] = LED_SEG_H;

    // page %= (LED_SEG_SG - LED_SEG_SA + 1);
    disp_str[1] = page + 1;

    // dat %= 100;
    disp_str[2] = dat / 10;
    disp_str[3] = dat % 10;
    led_putis(0, disp_str, LED_POS_MAX, 1);
}

void show_system_set_page(system_cfg_t *cfg, uchar page, uchar op) {
    uchar n = 0;
    uchar dat = 0;
    char xdata disp_str[LED_POS_MAX + 1] = {0};

    if (cfg == NULL) {
        return;
    }

    switch (page) {
    case SET_SYSTEM_PAGE_LIGHT:
        dat = cfg->led_light;
        _menu_data_deal_(&dat, op, LED_MAX_LIGHT, LED_MIN_LIGHT);
        cfg->led_light = dat;
        break;
    case SET_SYSTEM_PAGE_MIRROR:
        dat = cfg->led_mirror;
        _menu_data_deal_(&dat, op, 1, 0);
        cfg->led_mirror = dat;
        break;
    case SET_SYSTEM_PAGE_SECMOD:
        dat = cfg->main_mode;
        _menu_data_deal_(&dat, op, SYS_MAIN_MODE_MAX, 0);
        cfg->main_mode = dat;
        break;
    default:
        break;
    }

    page = page - SET_SYSTEM_PAGE_MIN;

    disp_str[0] = LED_SEG_P;

    // page %= (LED_SEG_SG - LED_SEG_SA + 1);
    disp_str[1] = page + 1;

    // dat %= 100;
    disp_str[2] = dat / 10;
    disp_str[3] = dat % 10;
    led_putis(0, disp_str, LED_POS_MAX, 1);
}

void show_autosleep_set_page(system_cfg_t *cfg, uchar page, uchar op) {
    uchar n = 0;
    uchar dat = 0;
    char xdata disp_str[LED_POS_MAX + 1] = {0};

    if (cfg == NULL) {
        return;
    }

    switch (page) {
    case SET_AUTO_SLEEP_SHOUR:
        dat = cfg->autosleep.s_hour;
        _menu_data_deal_(&dat, op, 23, 0);
        cfg->autosleep.s_hour = dat;
        break;
    case SET_AUTO_SLEEP_SMINUTE:
        dat = cfg->autosleep.s_min;
        _menu_data_deal_(&dat, op, 59, 0);
        cfg->autosleep.s_min = dat;
        break;
    case SET_AUTO_SLEEP_EHOUR:
        dat = cfg->autosleep.e_hour;
        _menu_data_deal_(&dat, op, 23, 0);
        cfg->autosleep.e_hour = dat;
        break;
    case SET_AUTO_SLEEP_EMINUTE:
        dat = cfg->autosleep.e_min;
        _menu_data_deal_(&dat, op, 59, 0);
        cfg->autosleep.e_min = dat;
        break;
    case SET_AUTO_SLEEP_ON:
        dat = cfg->autosleep.on;
        _menu_data_deal_(&dat, op, 1, 0);
        cfg->autosleep.on = dat;
        break;
    default:
        break;
    }

    page = page - SET_AUTO_SLEEP_MIN;

    disp_str[0] = LED_SEG_A;

    // page %= (LED_SEG_SG - LED_SEG_SA + 1);
    disp_str[1] = page + 1;

    // dat %= 100;
    disp_str[2] = dat / 10;
    disp_str[3] = dat % 10;
    led_putis(0, disp_str, LED_POS_MAX, 1);
}

void show_temp_page(void) {
    uint8 xdata sign = 0;
    uint8 xdata disp_temp = 0;
    uint16 xdata interger = 0;
    uint16 xdata decimal = 0;

    if (ds18b20_get_temp(&sign, &interger, &decimal) == RTN_OK) {
        if (sign) //负数
        {
            disp_temp = ((decimal >= 5) ? (interger + 1) : interger);
            disp_temp %= 100;
            led_puti(0, LED_SEG_HL, 1);     //负号
            led_puti(1, disp_temp / 10, 1); //十位
            led_puti(2, disp_temp % 10, 1); //个位
        } else                              //正数
        {
            disp_temp = (interger % 100);
            led_puti(0, disp_temp / 10, 1); //十位
            led_puti(1, disp_temp % 10, 1); //个位
            led_puti(2, decimal % 10, 1);   //小数
            if (led_get_mirror())           //小数点
            {
                //如果镜像显示，则小数点应该后移一位
                led_putb(2, LED_SEGB_SET(LED_SEGB_DP), 1, 1);
            } else {
                led_putb(1, LED_SEGB_SET(LED_SEGB_DP), 1, 1);
            }
        }
        led_puti(3, LED_SEG_CEL, 1); // 摄氏度
    }
}

void show_nonli_page(rtc_time_t *time_t) {
    uchar xdata i = 0;
    china_nonli_t xdata nonli_t = {0};

    if (time_t == NULL) {
        return;
    }

    if (china_nonli_get(time_t, &nonli_t) != RTN_OK) {
        return;
    }

    //为了区分，显示四个点
    led_puti(0, nonli_t.month / 10, 1);
    led_puti(1, nonli_t.month % 10, 1);
    led_puti(2, nonli_t.day / 10, 1);
    led_puti(3, nonli_t.day % 10, 1);

    for (i = 0; i < LED_POS_MAX; i++) {
        led_putb(i, LED_SEGB_SET(LED_SEGB_DP), 1, 1);
    }
}
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

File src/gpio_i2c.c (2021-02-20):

#include "gpio_i2c.h"

sbit GPIO_I2C_SDA = P3 ^ 4;
sbit GPIO_I2C_SCL = P3 ^ 3;

/*********I2C延时4us***********/
void gpio_i2c_wait(void) // 5us, @11.0592MHz
{
    uchar i;
    _nop_();
    _nop_();
    _nop_();
    i = 10;
    while (--i)
        ;
}

void gpio_i2c_nop(void) {
    _nop_();
    _nop_();
}

void gpio_i2c_init(void) {
    GPIO_I2C_SDA = 1;
    GPIO_I2C_SCL = 1;
    delay_xms(10);
}

/********开启I2C总线********/
uchar gpio_i2c_start(void) {
    GPIO_I2C_SDA = 1;
    GPIO_I2C_SCL = 1;
    gpio_i2c_wait();
    // if(!GPIO_I2C_SDA)
    //{
    //    return RTN_I2C_ERR;   //SDA线为低电平则总线忙,退出
    //}
    GPIO_I2C_SDA = 0;
    gpio_i2c_wait();
    // while(GPIO_I2C_SDA)
    //{
    //    return RTN_I2C_ERR; //SDA线为高电平则总线出错,退出
    //}
    GPIO_I2C_SCL = 0;
    gpio_i2c_wait();
    return RTN_I2C_OK;
}

/********关闭I2C总线*******/
void gpio_i2c_stop(void) {
    GPIO_I2C_SDA = 0;
    // GPIO_I2C_SCL = 0;
    gpio_i2c_wait();
    GPIO_I2C_SCL = 1;
    gpio_i2c_wait();
    GPIO_I2C_SDA = 1;
    gpio_i2c_wait();
}

/*********发送ACK*********/
void gpio_i2c_ack(void) {
    GPIO_I2C_SDA = 0;
    GPIO_I2C_SCL = 0;
    gpio_i2c_wait();
    GPIO_I2C_SCL = 1;
    gpio_i2c_wait();
    GPIO_I2C_SCL = 0;
}

/*********发送NOACK*********/
void gpio_i2c_nack(void) {
    GPIO_I2C_SDA = 1;
    GPIO_I2C_SCL = 0;
    gpio_i2c_wait();
    GPIO_I2C_SCL = 1;
    gpio_i2c_wait();
    GPIO_I2C_SCL = 0;
}

/*********读取ACK信号*********/
uchar gpio_i2c_waitack(void) //返回为:1=有ACK,0=无ACK
{
    uchar cnt = 0;
    GPIO_I2C_SCL = 0;
    GPIO_I2C_SDA = 1; //设置SDA为输入（其它类型的单片机需要配置IO输入输出寄存器）
    gpio_i2c_wait();
    GPIO_I2C_SCL = 1;
    gpio_i2c_wait();
    while (GPIO_I2C_SDA) {
        if ((cnt++) > 200) {
            GPIO_I2C_SCL = 0;
            gpio_i2c_wait();
            return RTN_I2C_ERR;
        }
    }
    GPIO_I2C_SCL = 0;
    gpio_i2c_wait();
    return RTN_I2C_OK;
}

/************I2C发送一个字节*************/
void gpio_i2c_sendbyte(uchar demand) //数据从高位到低位//
{
    uchar i = 8;

    while (i--) {
        GPIO_I2C_SCL = 0;
        gpio_i2c_nop();
        GPIO_I2C_SDA = (bit)(demand & 0x80);
        demand <<= 1;
        gpio_i2c_wait();
        GPIO_I2C_SCL = 1;
        gpio_i2c_wait();
    }
    GPIO_I2C_SCL = 0;
}

/*********I2C读入一字节*********/
uchar gpio_i2c_recvbyte(void) //数据从高位到低位//
{
    uchar i = 8;
    uchar ddata = 0;
    GPIO_I2C_SDA = 1; //设置SDA为输入（其它类型的单片机需要配置IO输入输出寄存器）
    while (i--) {
        ddata <<= 1; //数据从高位开始读取
        GPIO_I2C_SCL = 0;
        gpio_i2c_wait();
        GPIO_I2C_SCL = 1;
        gpio_i2c_wait(); //从高位开始 ddata|=GPIO_I2C_SDA;ddata<<=1
        if (GPIO_I2C_SDA) {
            ddata |= 0x01;
        }
    }
    GPIO_I2C_SCL = 0;
    return ddata;
}

/******I2C向指定地址写一个字节******/
uchar gpio_i2c_write(uchar dev_addr, uchar addr, uchar dat) {
    if (gpio_i2c_start() != RTN_I2C_OK) {
        return RTN_I2C_ERR;
    }
    gpio_i2c_sendbyte(dev_addr);
    gpio_i2c_waitack();
    gpio_i2c_sendbyte(addr); //设置写地址
    gpio_i2c_waitack();
    gpio_i2c_sendbyte(dat); //写数据
    gpio_i2c_waitack();
    gpio_i2c_stop();

    return RTN_I2C_OK;
}

/******I2C从指定地址读一个字节******/
uchar gpio_i2c_read(uchar dev_addr, uchar addr) {
    uchar dat;

    if (gpio_i2c_start() != RTN_I2C_OK) {
        return RTN_I2C_ERR;
    }
    gpio_i2c_sendbyte(dev_addr);
    if (gpio_i2c_waitack() != RTN_I2C_OK) {
        gpio_i2c_stop();
        return RTN_I2C_ERR;
    }
    gpio_i2c_sendbyte(addr); //设置要读的地址
    gpio_i2c_waitack();
    gpio_i2c_start(); //再次发送开始
    gpio_i2c_sendbyte(dev_addr + 1);
    gpio_i2c_waitack();
    dat = gpio_i2c_recvbyte(); //读数据
    gpio_i2c_nack();
    gpio_i2c_stop();
    return dat;
}

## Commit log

2020-06-22 add docs
    [miniclock_page.xlsx]
2020-06-24 update docs
    [miniclock_page.xlsx, miniclock_setcode.xlsx, 设置代码.xlsx]
